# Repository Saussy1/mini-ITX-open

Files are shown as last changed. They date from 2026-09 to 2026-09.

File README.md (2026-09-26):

# 3D Printed Mini-ITX PC Case (SFX PSU)

<p align="center">
  Assembled case
  Rear I/O
</p>

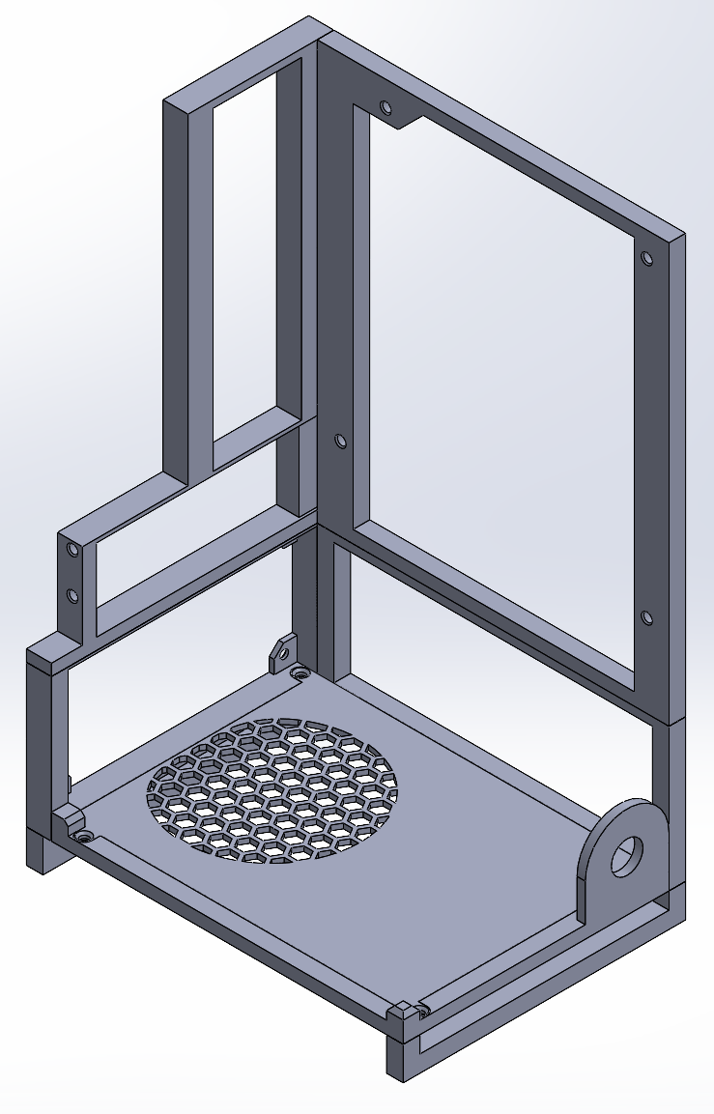
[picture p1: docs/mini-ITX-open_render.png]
CAD render


## Introduction

A custom, 3D printed open-frame PC case built to house a Mini-ITX motherboard and an SFX power supply. I designed this to be a quick, cheap, headless PC for server hosting.

### Design Features

- Supports Mini-ITX motherboards and SFX power supplies
- 142 × 191 mm (5.6 × 7.5 in) footprint
- 8.25 L volume
- Rear PSU intake vent
- Raised bottom with GPU intake
- Prints without supports
- Designed for PETG

### Compatibility

| Component | Limit |
| --- | --- |
| Motherboard | Mini-ITX |
| Power supply | SFX |
| GPU | Any (open frame) |
| Printer bed | 250 × 210 × 220 mm or larger (designed on a Prusa MK4S) |

## Repository Contents

| Folder / File | Contents |
| --- | --- |
| `cad/solidworks/` | Native SolidWorks parts and assembly (SolidWorks 2025) |
| `cad/step/` | STEP (AP214) exports for any CAD program |
| `stl/` | Print-ready STL files |
| `docs/` | Reference drawings, photos, and renders |
| [`BOM.csv`](BOM.csv) | Bill of materials: printed parts, filament (~312 g PETG), and hardware |

## Design Considerations

The `docs/` folder includes the reference drawings used for the CAD dimensions. I've found them accurate for this project. If you modify the design, check your changes against these drawings so your components still fit.

### GPU Airflow

The case is designed with GPU airflow in mind: the bottom is raised and has an intake for the GPU.

### Printing and Assembly

The case was designed in SolidWorks to print on a Prusa MK4S (250 × 210 × 220 mm bed) without supports, which saves filament and print time.

The frame is held together with 3D printed pins. Printer tolerances vary, so print a pin first, test the fit, and adjust if needed.

**Tools needed:** soldering iron (for the heat-set inserts) and a Phillips screwdriver.

### Material

PC components generate heat, so PETG is recommended. It handles heat better than PLA, which can soften near warm components. If you use other materials, print and build at your own risk.

## License

The design files in this repository are licensed under [CC BY-NC 4.0](https://creativecommons.org/licenses/by-nc/4.0/). You're welcome to remix, modify, and build on this design for personal projects. Please credit "Jack Saussy" and link back to this repository. Commercial use, including selling files or printed copies, is not permitted.

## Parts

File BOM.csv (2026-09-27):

Item | Type | Part | Qty | Material / Spec | Source / Link | Notes
1 | Printed | Big L | 1 | PETG | stl/big_L.stl
2 | Printed | Bottom | 1 | PETG | stl/bottom.stl
3 | Printed | ITX IO | 1 | PETG | stl/itx_io.stl
4 | Printed | ITX side | 1 | PETG | stl/itx_side.stl
5 | Printed | PSU IO | 1 | PETG | stl/psu_io.stl
6 | Printed | PSU side | 1 | PETG | stl/psu_side.stl
7 | Printed | Foot | 2 | PETG | stl/foot.stl
8 | Printed | Pin | 15 | PETG | stl/pin.stl
9 | Filament | Elegoo Rapid PETG | 312 g | PETG, 1.75 mm | https://us.elegoo.com/products/rapid-petg-filament-1-75mm-colored-1kg | Total for all printed parts; one 1 kg spool is plenty
10 | Hardware | Male-Female Hex Standoff, 3/16" Hex, 3/8" Long, 6-32 | 4 | Brass | https://www.mcmaster.com/92700A112
11 | Hardware | Symmetrical Heat-Set Insert, 6-32, 0.281" Installed Length | 10 | Brass | https://www.mcmaster.com/93502A121
12 | Hardware | Phillips Flat Head Screw, 6-32, 5/16" Long | 4 | Brass | https://www.mcmaster.com/92480A842 | Must be flat head to clear PSU
13 | Hardware | Phillips Pan Head Screw, 6-32, 1/4" Long | 6 | Brass | https://www.mcmaster.com/94070A144 | Can be subbed with pan head screws
15 | Hardware | NOYITO 16 mm Power Button, Blue LED Power Symbol, PC Chassis Switch Extension Cable | 1 | 16 mm, blue LED | https://www.amazon.com/dp/B07PPDHKDT

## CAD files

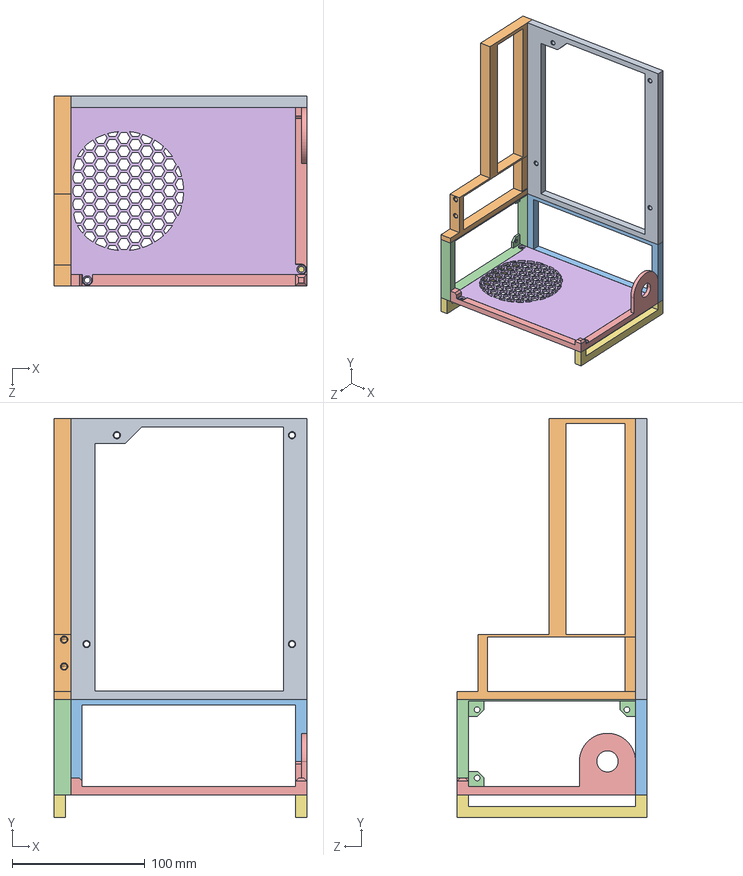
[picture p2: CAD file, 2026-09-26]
cad/step/full_case.STEP
190.7 x 300.9 x 142.9 mm
itx_side
itx_io
psu_side
psu_io
big_L
bottom
feet x 2

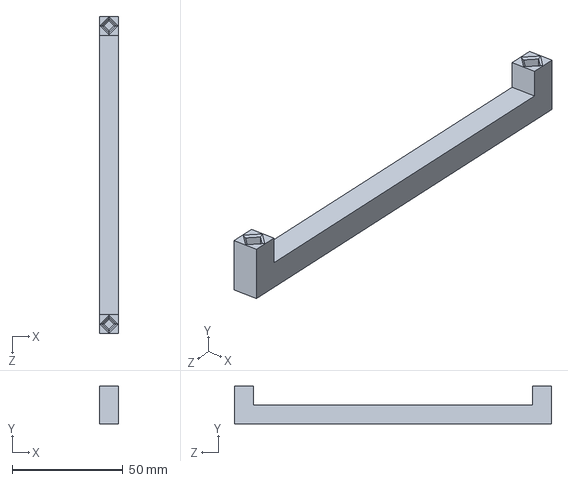
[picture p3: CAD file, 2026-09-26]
cad/solidworks/foot.SLDPRT
8.47 x 16.9 x 142.9 mm

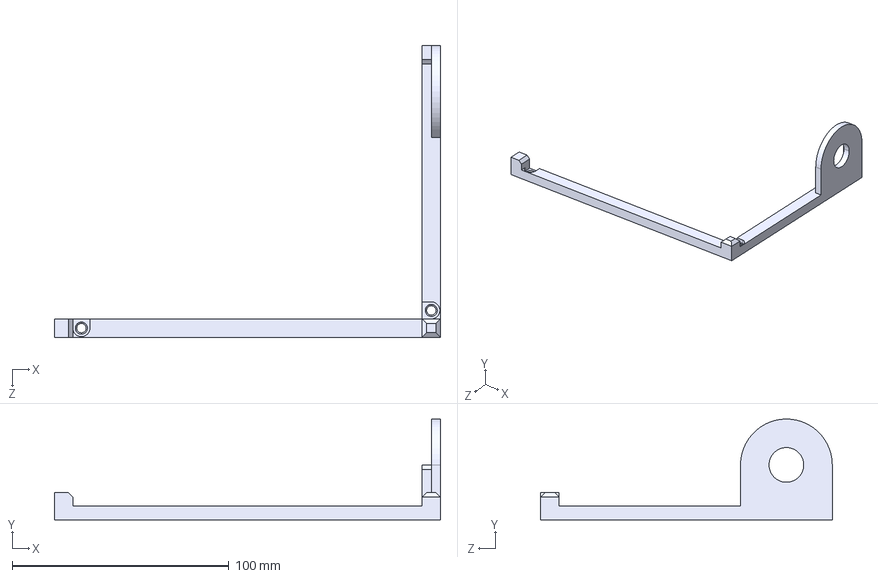
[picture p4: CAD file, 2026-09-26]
cad/step/big_L.STEP
178.0 x 46.6 x 134.5 mm

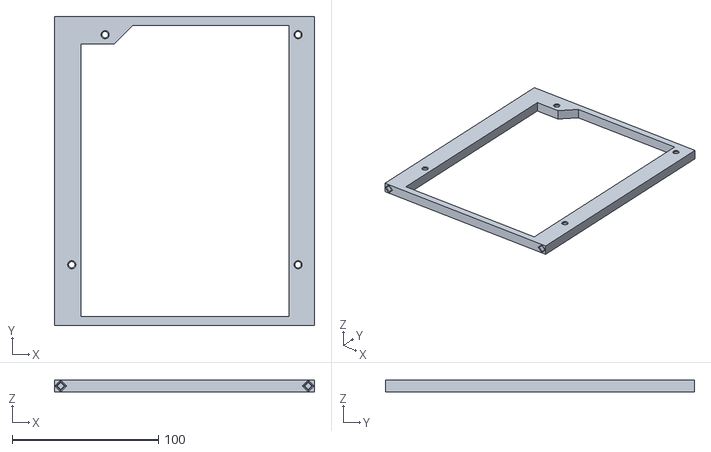
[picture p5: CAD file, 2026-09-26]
stl/micro itx side.STL
178.0 x 211.8 x 8.47

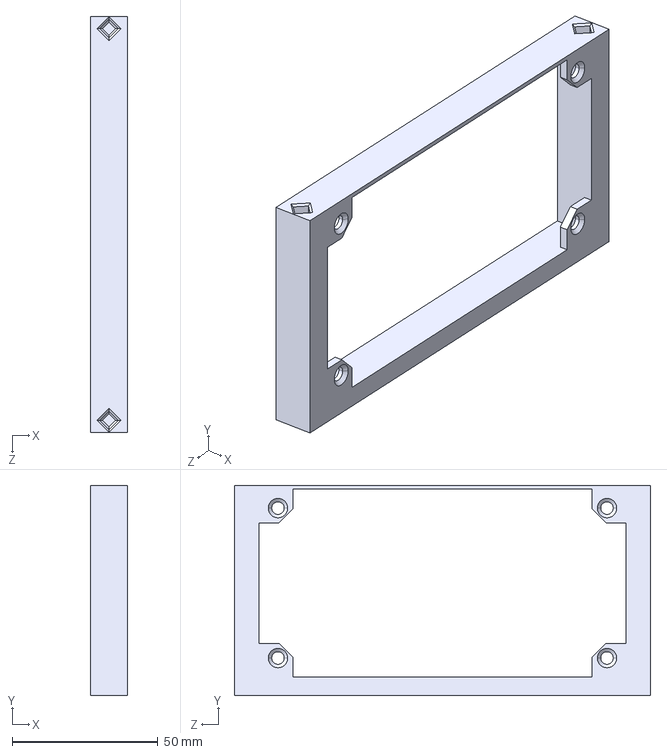
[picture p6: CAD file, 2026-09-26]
cad/step/psu_io.STEP
12.7 x 72.1 x 142.9 mm

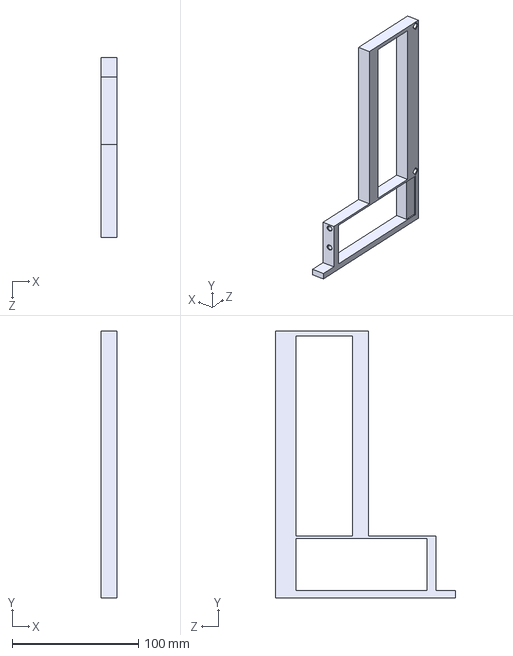
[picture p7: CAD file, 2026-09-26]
cad/step/itx_io.STEP
12.7 x 211.8 x 142.9 mm

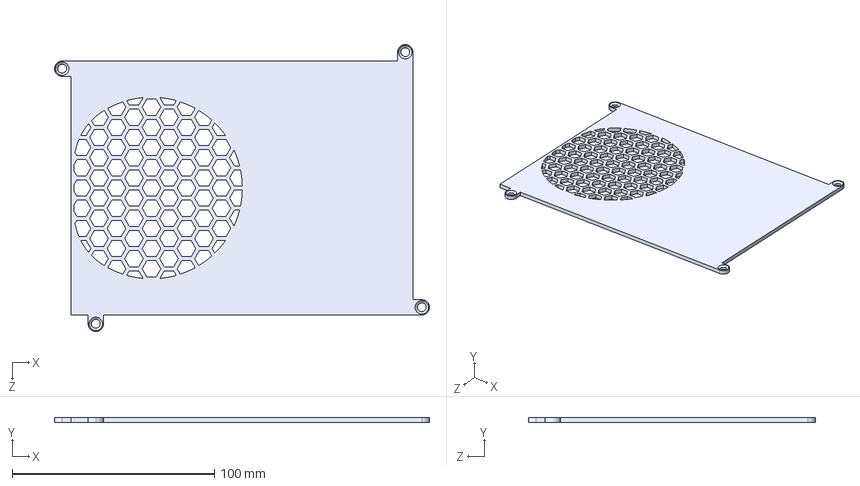
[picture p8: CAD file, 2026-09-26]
cad/step/bottom.STEP
185.6 x 2.54 x 142.1 mm

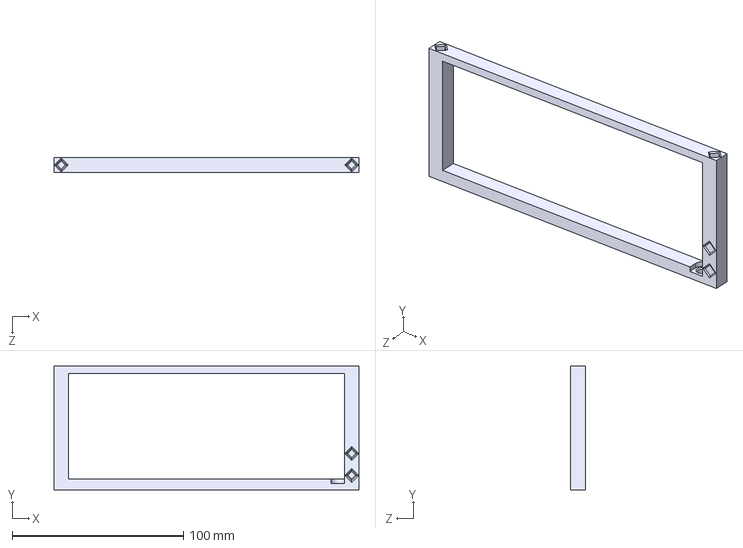
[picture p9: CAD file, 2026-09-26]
cad/step/psu_side.STEP
178.0 x 72.1 x 8.47 mm

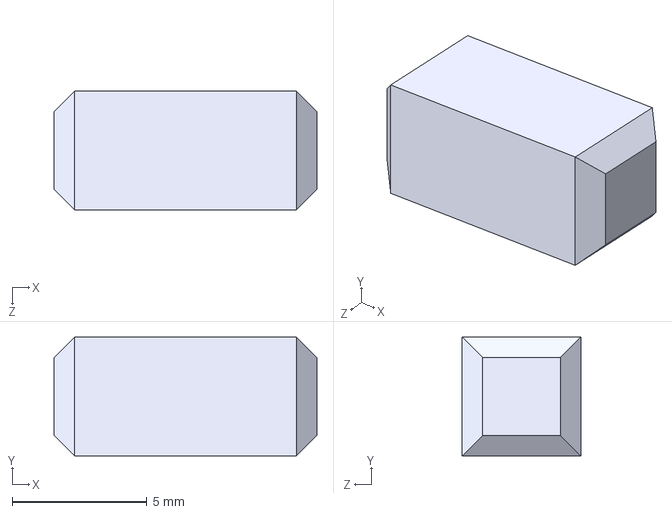
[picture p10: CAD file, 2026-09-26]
cad/step/pin.STEP
9.76 x 4.40 x 4.40 mm

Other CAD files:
cad/step/itx_side.STEP
cad/step/feet.STEP
cad/solidworks/big_L.SLDPRT
cad/solidworks/bottom.SLDPRT
cad/solidworks/full_case.SLDASM
cad/solidworks/itx_io.SLDPRT
cad/solidworks/itx_side.SLDPRT
cad/solidworks/pin.SLDPRT
cad/solidworks/psu_io.SLDPRT
cad/solidworks/psu_side.SLDPRT
stl/big_L.STL
stl/bottom.STL
stl/feet.STL
stl/itx_io.STL
stl/pin.STL
stl/psu_io.STL
stl/psu_side.STL

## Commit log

2026-09-26 Initial upload
    [BOM.csv, big_L.SLDPRT, big_L.STEP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]
2026-09-26 Enhance README introduction with design purpose
    Expanded introduction to include purpose of the PC case.
2026-09-27 Update BOM.csv with new power button entry
    Added a new hardware item for the power button and ensured proper formatting.
    [BOM.csv]
2026-09-27 Add substitution note for pan head screws
    Updated BOM.csv to include substitution note for pan head screws.
    [BOM.csv]
